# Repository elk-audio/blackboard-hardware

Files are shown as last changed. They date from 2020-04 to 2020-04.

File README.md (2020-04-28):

# Blackboard Hardware project

Full hardware project for the [Blackboard UI hat](https://elk.audio/blackboard/) to be used together with Elk Pi.

Directory contents:

  * [altium-files](altium-files): Full Altium designer project
  * [production-files](production-files): Gerber and drill files ready for PCB manufacturing, plus pick&place assembly drawings
  * [blackboard-bill-of-materials.xlsx](blackboard-bill-of-materials.xlsx): Bill Of Materials (BOM)
  * [blackboard-schematics.pdf](blackboard-schematics.pdf): schematics capture file

---
Copyright 2020 *Modern Ancient Instruments Networked AB*, dba *Elk*

<br />This work is licensed under a <a rel="license" href="http://creativecommons.org/licenses/by-sa/4.0/">Creative Commons Attribution-ShareAlike 4.0 International License</a>.

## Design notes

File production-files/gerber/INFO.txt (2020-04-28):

ELK SIKA UI - rev 2
(11 Feb 2020 - 02:25 PM)

PCB Specification
-------------------------------------------------
Copper Layers:      4
Material:           Standard FR4 1.6mm
Finish:             Lead free HASL on 1oz copper
Solder Mask:        Matt Black
Silk:               White (Both sides)
Dimensions:         155 x 95mm

Files
-------------------------------------------------
Top copper:         sika_UI.GTL
Inner copper 1:     sika_UI.G2L
Inner copper 2:     sika_UI.G3L
Bottom copper:      sika_UI.GBL
Top soldermask:     sika_UI.GTS
Bottom soldermask:  sika_UI.GBS
Top paste:          sika_UI.GTP
Bottom paste:       sika_UI.GBP
Top Silk:           sika_UI.GTO
Bottom Silk:        sika_UI.GBO
Board outline:      sika_UI.GKO
Holes:              sika_UI-RectHoles.TXT
Holes:              sika_UI-RoundHoles.TXT
Holes:              sika_UI-SlotHoles.TXT

Notes
-------------------------------------------------
- Please do not insert any extra markings into 
  the silkscreen. No board ID or other tags.

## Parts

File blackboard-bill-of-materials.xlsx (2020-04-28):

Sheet: Internal Copy - LED Goggles - B
BLACKBOARD | Bill of Materials 30 Mar 2020
Part Name | Part Number | Vendor | Designator | Footprint | Quantity | Primary Supplier | Assembly Notes
100nF 25V Cap (X7R 10%) | 885012206071 | Wurth | C5, C8, C11 - C17 | 0603 | 9 | Mouser: 710-885012206071 (https://www.mouser.se/ProductDetail/710-885012206071)
10nF 16V Cap (X7R 10%) | 885012206040 | Wurth | C6, C7 | 0603 | 2 | Mouser: 710-885012206040 (https://www.mouser.se/ProductDetail/710-885012206040)
2.2uF 10V (X7R 10%) | 0603B225K100CT | Walsin | C1 - C4, C9 | 0603 | 5 | Mouser: 791-0603B225K100CT (https://www.mouser.se/ProductDetail/791-0603B225K100CT)
10uF 25V Cap (X7R 10%) | 0603ZD106KAT2A | AVX | C10 | 0603 | 1 | Mouser: 581-0603ZD106KAT2A (https://www.mouser.se/ProductDetail/581-0603ZD106KAT2A)
820R Res (Thick Film 1%) | SFR03EZPF8200 | Rohm | R10 - R13 | 0603 | 4 | Mouser: 755-SFR03EZPF8200 (https://www.mouser.se/ProductDetail/755-SFR03EZPF8200)
1.5k Res (Thick Film 1%) | CRCW06031K50FKEAC | Vishay | R1 - R9, R19, R25 - R27, R33 - R36, R38 | 0603 | 18 | Mouser: 71-CRCW06031K50FKEAC (https://www.mouser.se/ProductDetail/Vishay-Dale/CRCW06031K50FKEAC)
10k Res (Thick Film 5%) | CRCW060310K0JNEBC | Vishay | R15 - R18, R21 - R24, R28 - R32, R37 | 0603 | 14 | Mouser: 71-CRCW060310K0JNEBC (https://www.mouser.se/ProductDetail/71-CRCW060310K0JNEBC)
390k Res (Thick Film 1%) | CR0603-FX-3903ELF | Bourns | R20 | 0603 | 1 | Mouser: 652-CR0603FX-3903ELF (https://www.mouser.se/ProductDetail/Bourns/CR0603-FX-3903ELF?qs=sGAEpiMZZMu61qfTUdNhG6LqqFhkr6pUvE/rOSEI3N4=)
Red SMD LED | APTD1608LSURCK (https://www.mouser.se/datasheet/2/216/APTD1608LSURCK-1102303.pdf) | KingBright | D1 - D9 | 0603 | 9 | Mouser: 604-APTD1608LSURCK (https://www.mouser.se/ProductDetail/604-APTD1608LSURCK) | Cathode faces east
Automatic Reset IC | APX803-29SAG-7 (https://www.mouser.se/datasheet/2/115/APX803-D-Not-Recommended-1512836.pdf) | Diodes Inc | U1 | SOT23 | 1 | Mouser: 621-APX803-29SAG-7 (https://www.mouser.se/ProductDetail/621-APX803-29SAG-7)
Switch DPDT PTH | OS202011MS2QN1 (https://www.mouser.se/datasheet/2/60/os-1382783.pdf) | C&K | S9 | PTH | 1 | Mouser: 611-OS202011MS2QN1 (https://www.mouser.se/ProductDetail/611-OS202011MS2QN1)
Switch DPDT SMD | JS202011JAQN (https://www.mouser.se/datasheet/2/60/os-1382783.pdf) | C&K | S1, S2, S6, S7 | SMD | 4 | Mouser: 611-JS202011JAQN (https://www.mouser.se/ProductDetail/CK/JS202011JAQN)
Rotary Encoder 20mm | PEC11R-4120F-S0018 (https://www.mouser.se/datasheet/2/54/PEC11R-777457.pdf) | Bourns | EN1 | PTH | 1 | Mouser: 652-PEC11R-4120F-S18 (https://www.mouser.se/ProductDetail/Bourns/PEC11R-4120F-S0018)
10k Rotary Linear Pot | BK10 (http://www.thonk.co.uk/wp-content/uploads/2014/10/R0904N_Thonk.pdf) | Thonk | POT5 | PTH | 1 | Thonk: BK10-SONG-HUEI (https://www.thonk.co.uk/shop/ttpots/)
5k Slide Pot \w Red LED | PTL20-15R1-502B2 (https://www.mouser.se/datasheet/2/54/PTL-777483.pdf) | Bourns | POT1 - POT4 | PTH | 4 | Mouser: 652-PTL20-15R1-502B2 (https://www.mouser.se/ProductDetail/Bourns/PTL20-15R1-502B2) | Soldered as straight as possible
1/4” Stereo Jack | NMJ6HFD2 (http://www.neutrik.us/en-us/plugs-jacks/m-series/nmj6hfd2) | Neutrik | J23 - J26 | PTH | 4 | Mouser: 550-20301 (https://www.mouser.se/ProductDetail/Neutrik/NMJ6HFD2?qs=sGAEpiMZZMv0W4pxf2HiV1EdQ7jplh8o7nfFBXowtLE=)
3.5mm Side Stereo Jack | SJ-3523-SMT-TR (https://www.mouser.se/datasheet/2/670/sj-352x-smt_series-1313220.pdf) | CUI Devices | J32, J35 | SMD | 2 | Mouser: 490-SJ-3523-SMT-TR (https://www.mouser.se/ProductDetail/CUI-Devices/SJ-3523-SMT-TR) | Requires extra soldering for strength
3.5mm Top Stereo Jack | PJ301BM | Thonk | J3 - J22 | PTH | 20 | Thonk: PJ301BM (https://www.thonk.co.uk/shop/3-5mm-jacks/) | Soldered as straight as possible
Tactile Button Black PTH | 1-1825910-4 (https://www.mouser.se/datasheet/2/418/NG_CD_1825910_C10-1245000.pdf) | TE | S12 | PTH | 1 | Mouser: 506-1-1825910-4 (https://www.mouser.se/ProductDetail/TE-Connectivity-Alcoswitch/1-1825910-4)
Tactile Button Red PTH | 1-1825910-5 (https://www.mouser.se/datasheet/2/418/NG_CD_1825910_C10-1245000.pdf) | TE | S3 - S5, S8, S10, S11, S13, S14 | PTH | 8 | Mouser: 506-FSM8JAH (https://www.mouser.se/ProductDetail/506-FSM8JAH)
.1” Pin Header 2x20 PTH | 41013127 | Electrokit | J27, J28 | PTH | 2 | Elektrokit: 41013127 (https://www.electrokit.com/produkt/hylslist-2-54mm-2x20p-stackbar/)
.1” Pin Header 2x13 PTH | 41013127 | Electrokit | J1, J2 | PTH | 2 | Elektrokit: 41013127 (https://www.electrokit.com/produkt/hylslist-2-54mm-2x13p-stackbar/)
.1” Pin Header 2x3 SMD | M20-7870342 (https://www.mouser.se/datasheet/2/181/M20-787-1132664.pdf) | Harwin | J29 - J31, J33, J34 | SMD | 5 | Mouser: 855-M20-7870342 (https://www.mouser.se/ProductDetail/Harwin/M20-7870342?qs=/ha2pyFaduikSE1G3wvXnK27U4sxIe9IKbMXQzcjpuE=)
1.3” OLED Display | KWH0130UL01 | Formike | OLED1 | SMD | 1 | Direct Supplier
Rotary Dial D Shaft | Sifam Large Soft D 12mm | Thonk | - | Hardware | 1 | Thonk (http://www.apple.com/uk)
Double Side Tape 10x10mm |  | 3M | - | Hardware | 1 | Any
No not populate | - | - | R14 | - | 1 | -

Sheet: Internal Copy - Errata
Errata
Date | Issue | On Line
2020-03-30 | APX803-40SAG-7 is incorrect 4Vth part. Replaced to APX803-29SAG-7 | 12

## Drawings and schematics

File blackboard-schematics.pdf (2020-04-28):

# 2.54mm CONNECTORS

# AUDIO, CV, GATES

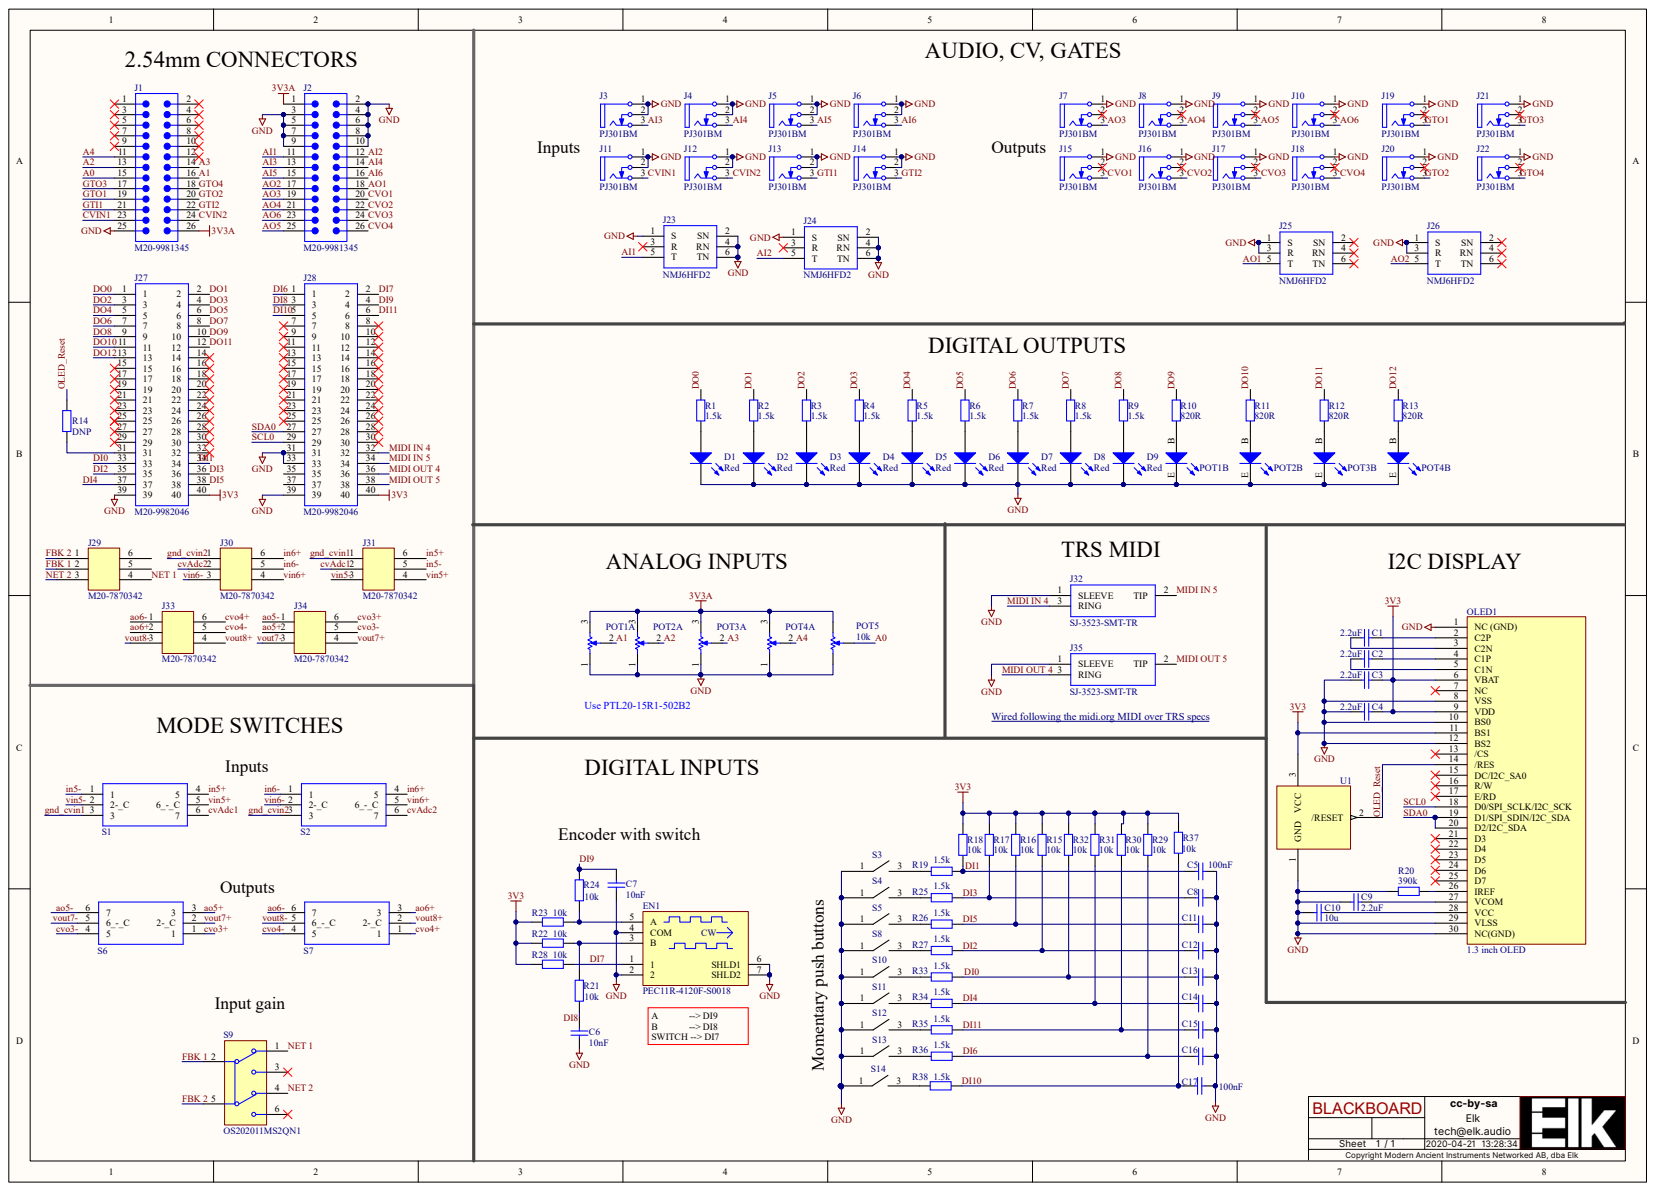
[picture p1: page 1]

Wired following the midi.org MIDI over TRS specs

Copyright Modern Ancient Instruments Networked AB, dba Elk
